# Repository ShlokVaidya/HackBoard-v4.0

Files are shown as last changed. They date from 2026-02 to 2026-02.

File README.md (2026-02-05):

# HackBoard-v4.0

A custom 75% mechanical gaming keyboard featuring a Raspberry Pi Pico 2 microcontroller, VIA keyboard configurator support, and a rotary encoder for media control. This project combines elegant PCB design, modular mechanical construction, and open-source firmware for a fully customizable typing experience.

## Electronics Design

The HackBoard v4.0 uses a matrix-based keyboard design with a Raspberry Pi Pico W as the main controller. Each switch connects to the microcontroller through a matrix circuit, with individual SOD-123 diodes preventing ghosting and ensuring reliable key registration.

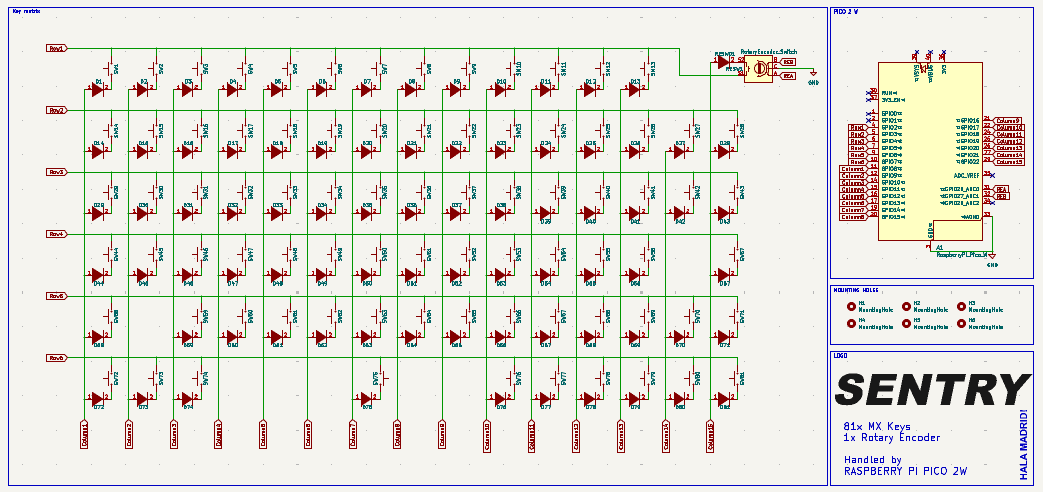
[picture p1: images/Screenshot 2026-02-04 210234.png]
Schematic showing microcontroller and switch matrix connections


The circuit is optimized for minimal latency and power efficiency, with the Pico's USB connectivity enabling VIA firmware for instant key remapping without recompilation.

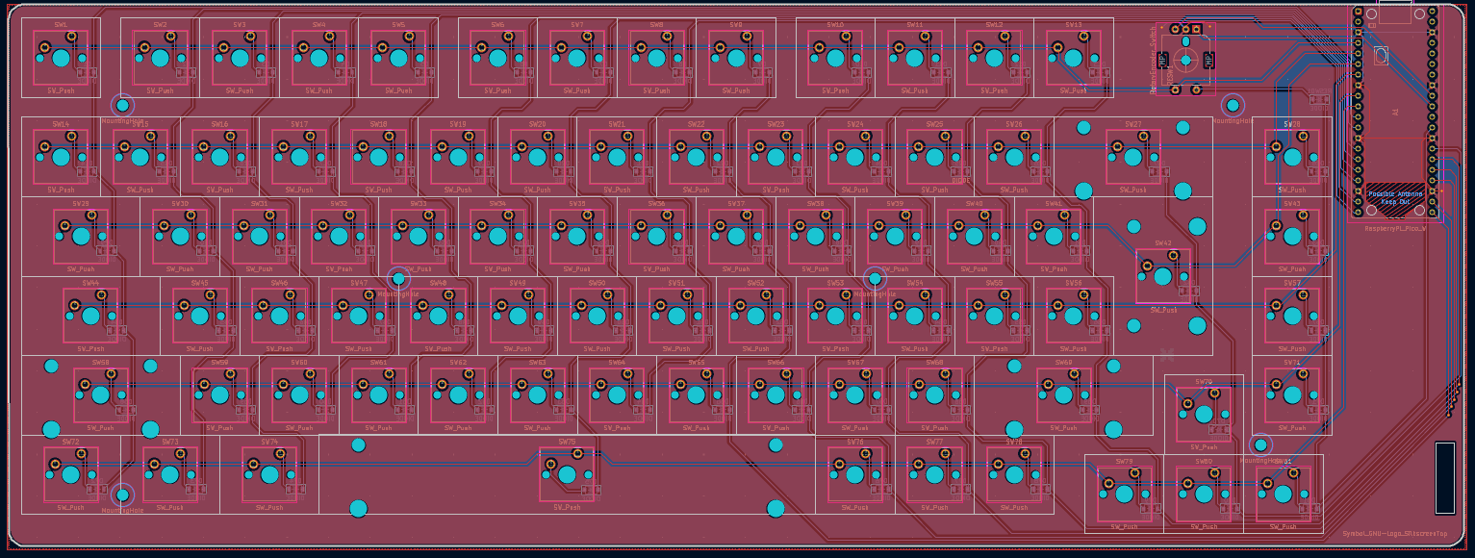
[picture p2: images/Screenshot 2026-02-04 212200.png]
Matrix layout and electrical connections


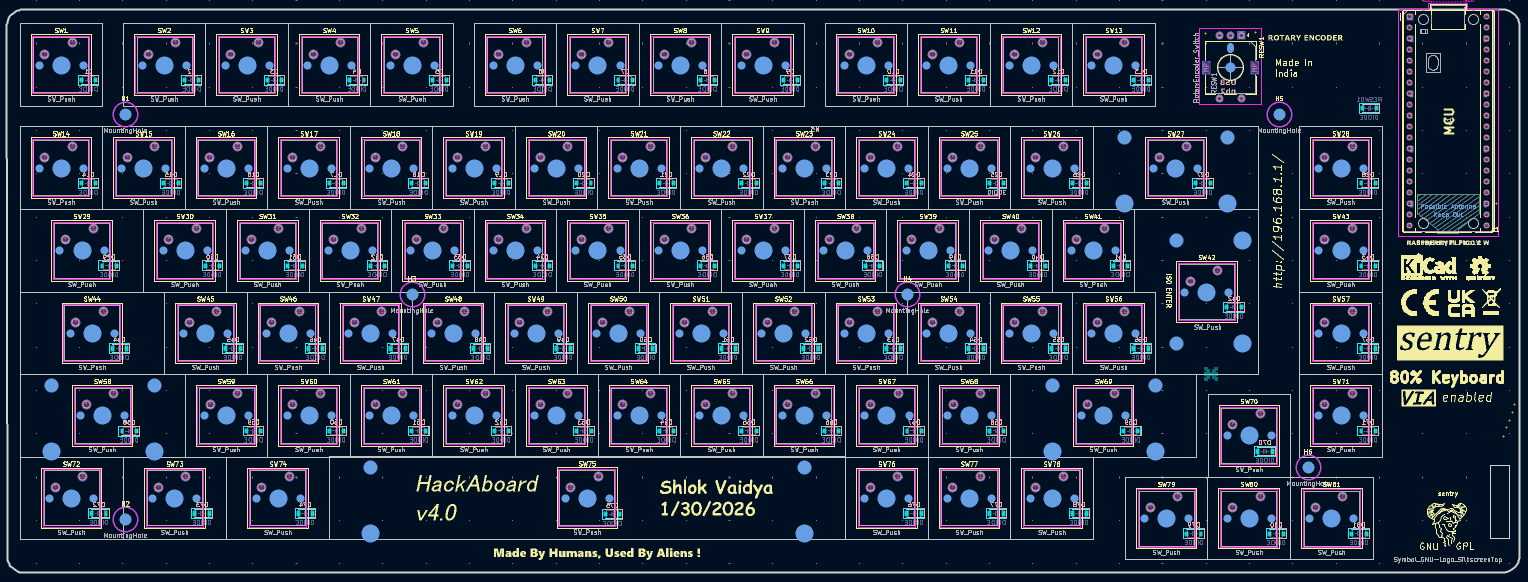
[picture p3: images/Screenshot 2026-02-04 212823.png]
Detailed schematic routing for power distribution and signal integrity


## PCB Design

The PCB is a carefully routed four-layer board that integrates the switch matrix, microcontroller, and rotary encoder in a compact 75% layout. Signal integrity and ground plane continuity were prioritized for minimal EMI and stable operation.

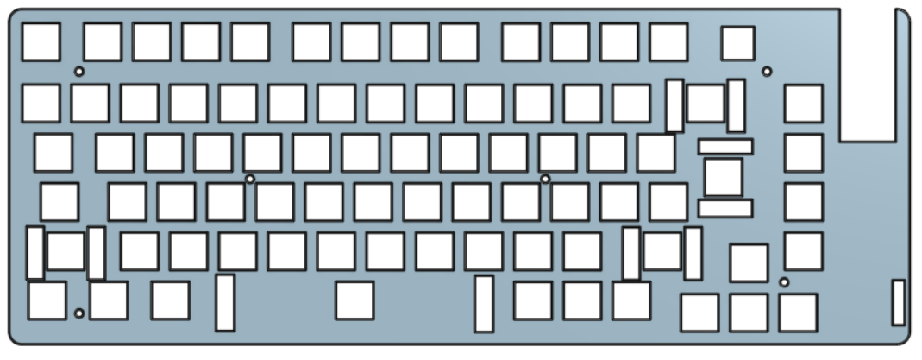
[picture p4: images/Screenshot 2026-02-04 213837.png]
PCB Layout - Component Placement Layer


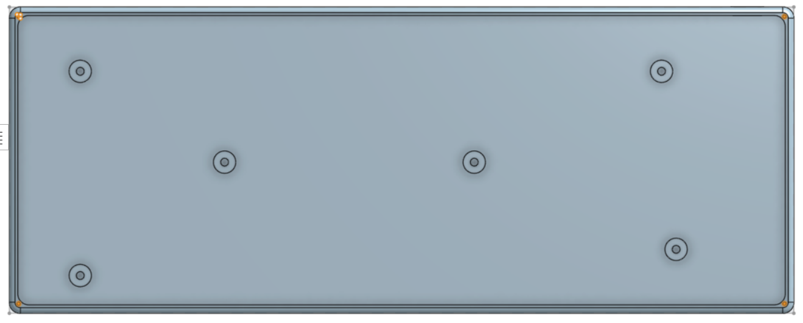
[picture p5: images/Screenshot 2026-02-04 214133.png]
PCB Layout - Top Signal Layer with trace routing


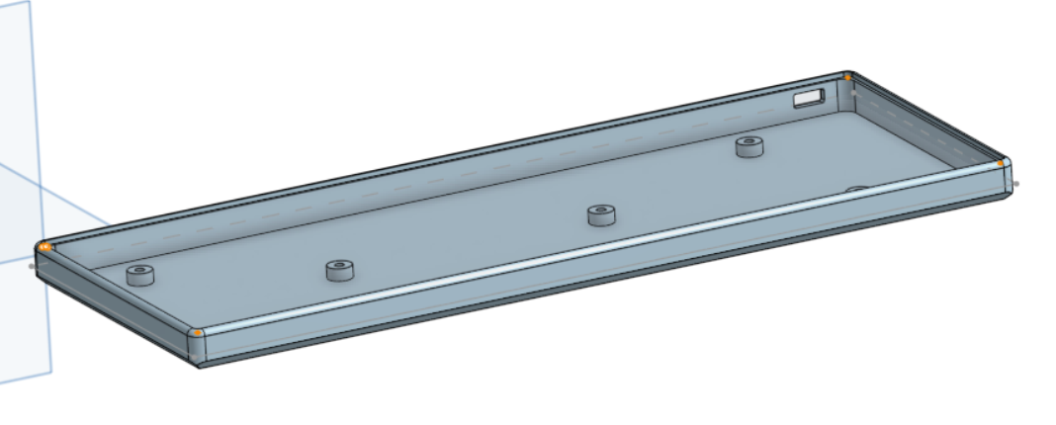
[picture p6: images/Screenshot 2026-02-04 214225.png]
PCB Layout - Bottom Signal Layer showing efficient routing


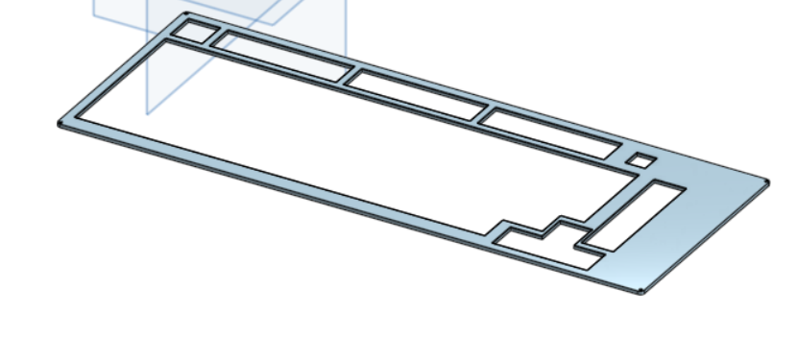
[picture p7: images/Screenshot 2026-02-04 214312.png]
PCB 3D visualization showing component heights and assembly clearance


The design includes mounting points for the stabilizers, hotswap sockets for all key positions, and a dedicated encoder footprint. Via stitching around signal traces ensures proper grounding.

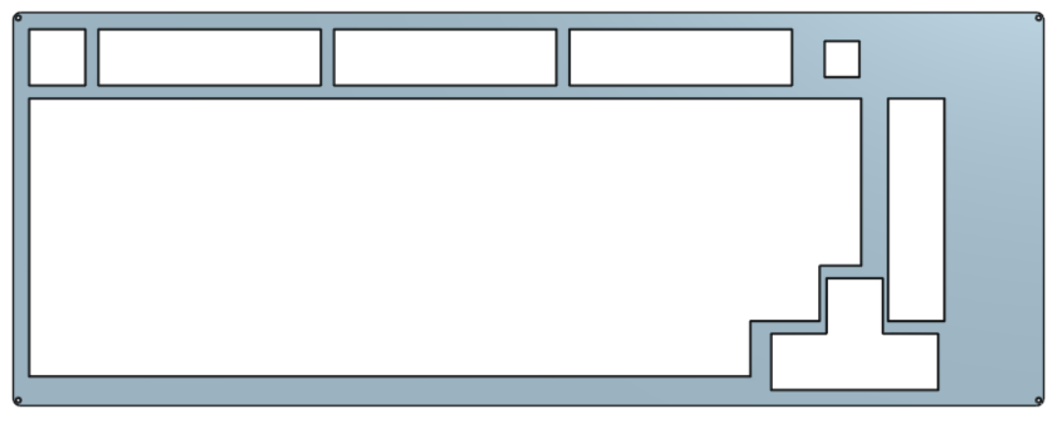
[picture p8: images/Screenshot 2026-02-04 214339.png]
PCB Assembly Layout with component designators


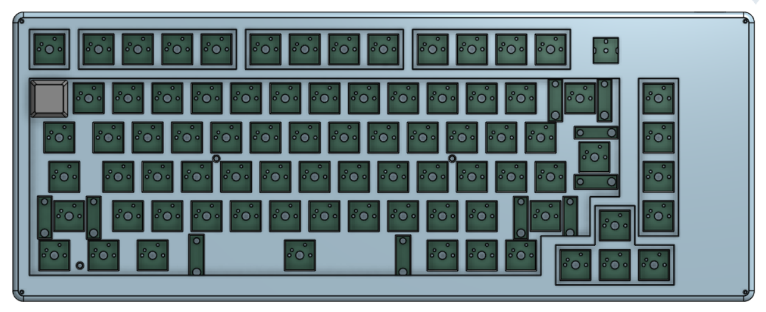
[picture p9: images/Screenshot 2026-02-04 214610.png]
Finished PCB layout ready for fabrication


## Mechanical Design

### Plate Design

The plate provides structural rigidity and supports the stabilizers while maintaining compatibility with Cherry MX switches across all positions.

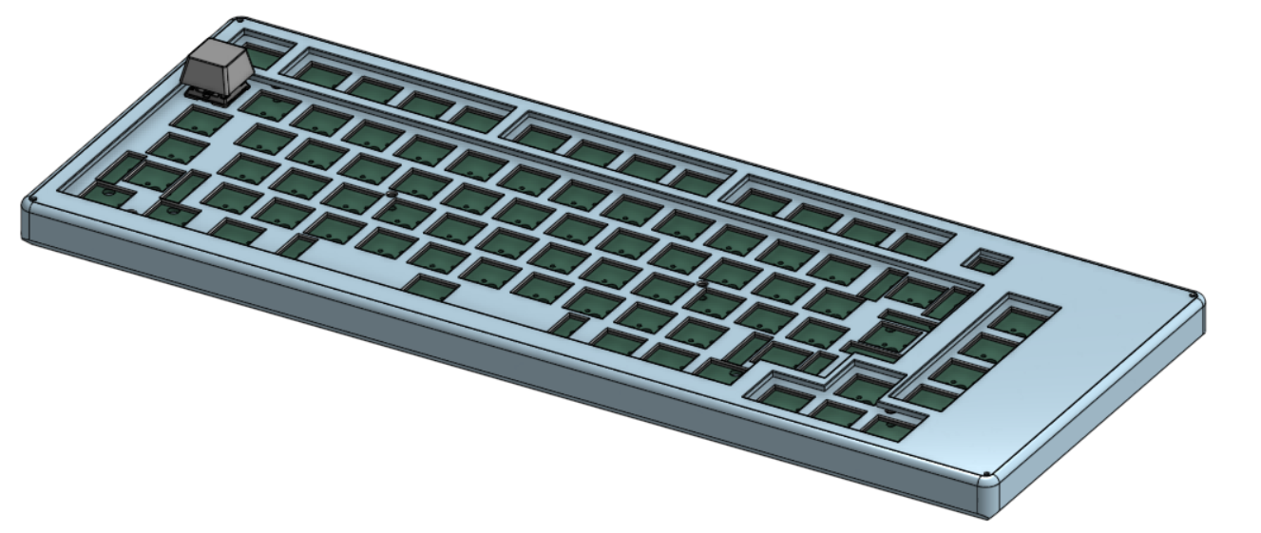
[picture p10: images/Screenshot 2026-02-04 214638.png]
Plate Assembly - Engineering drawing and mounting holes


### Case Design

The case forms the keyboard body and houses the PCB, plate, stabilizers, and all mounting hardware. The design balances acoustics, durability, and aesthetic appeal.

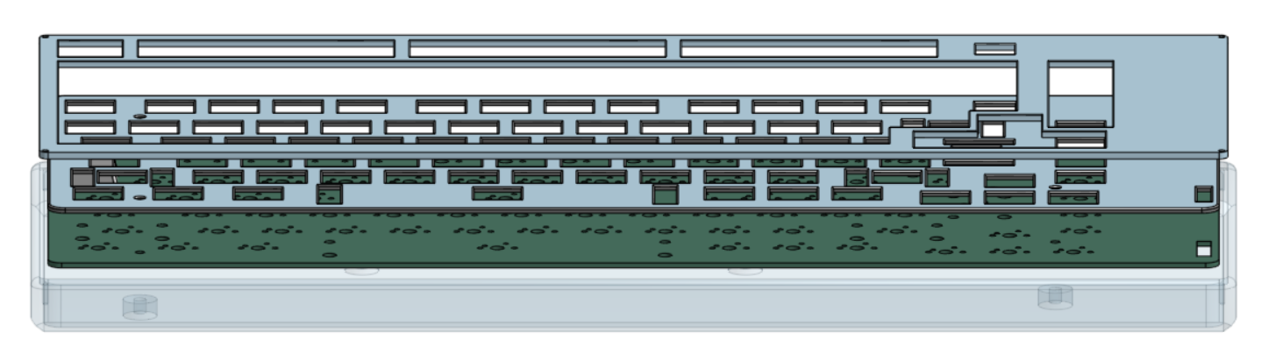
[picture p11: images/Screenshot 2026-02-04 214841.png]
Case - 3D CAD render showing overall form and enclosure


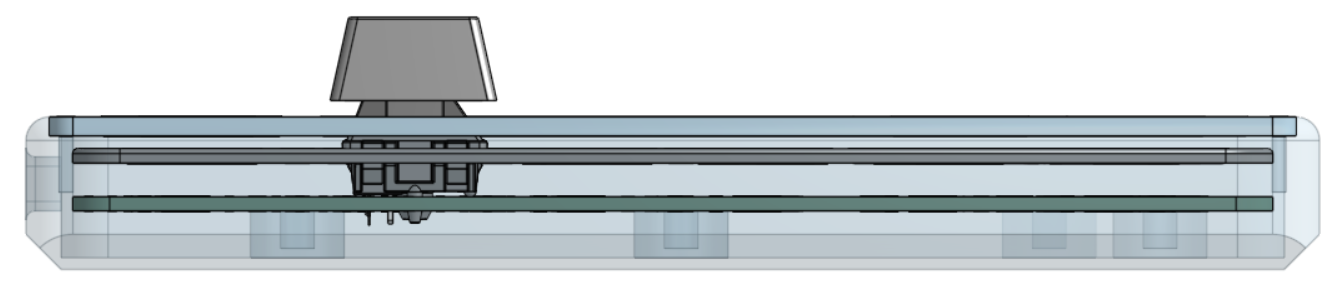
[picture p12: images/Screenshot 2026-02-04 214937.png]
Case - Bottom detail showing mounting features


## Bill of Materials

| Component Name | Qty | Price (₹) | Price ($) | Vendor |
|---|-----|---|---|---|
| Raspberry Pi Pico 2 / Pico 2 W | 1 | ₹635 | $8.00 | [Robu.in](https://robu.in/) |
| Custom 75% Keyboard PCB | 1 | ₹4,692 | $52.00 | [PowerPCB](https://powerpcb.com/) |
| MX Mechanical Switches (Akko V5) | 84 | ₹2,398 | $27.00 | [StacksKB](https://stackskb.com/store/akko-v5-creamy-yellow-pro-switch-pack-of-45/) |
| Clear Screw-In Stabilizer | 4 + 1 (6.25U) | ₹1,595 | $18.00 | [StacksKB](https://stackskb.com/store/durock-clear-screw-in-stabilizers-v2/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) |
| 1N4148W Diodes (SOD-123) | 84 | ₹122 | $1.50 | [Robu.in](https://robu.in/) |
| Rotary Encoder (with push button) | 1 | ₹55 | $1.00 | [Robu.in](https://robu.in/product/hongyan-ec11h-7ce15p1zd15f7-rotary-encoder-with-push-button-switch-vertical-plug-in-5-pin-360-degree/) |
| Keycap Set (75% compatible) | 1 set | ₹2,399 | $27.00 | [Robu.in](https://robu.in/) |
| M2.5 Screws | 7 | ₹43.30 | $0.50 | [OnlyScrews.in](https://onlyscrews.in/) |
| M2.5 Heat-set Inserts | 7 | ₹14.00 | $0.20 | [OnlyScrews.in](https://onlyscrews.in/) |
| M1.6 Screws | 5 | ₹16.00 | $0.20 | [OnlyScrews.in](https://onlyscrews.in/) |
| Shipping (Robu.in) | 1 | ₹49 | $0.59 | [Robu.in](https://robu.in/) |
| Shipping (OnlyScrews.in) | 1 | ₹60 | $0.72 | [OnlyScrews.in](https://onlyscrews.in/) |

---

## Total Cost

**Total (INR): ₹12,078.30**  
**Total (USD): $136.71**

## Project Files

```
PCB/
├── HackBoard v4.kicad_sch    # KiCad schematic
├── HackBoard v4.kicad_pcb    # KiCad PCB layout
├── HackBoard v4.kicad_pro    # KiCad project settings

CAD/
├── Case.step                 # Case 3D model (STEP format)
├── plate.step                # Plate 3D model (STEP format)
├── Top Cover.step            # Top cover 3D model (STEP format)

production/
├── bom.csv                   # Bill of Materials
├── designators.csv           # Component designators
├── positions.csv             # Pick-and-place coordinates
└── netlist.ipc               # IPC netlist format
```

## License

This project is licensed under the MIT License. See [LICENSE](LICENSE) for details.

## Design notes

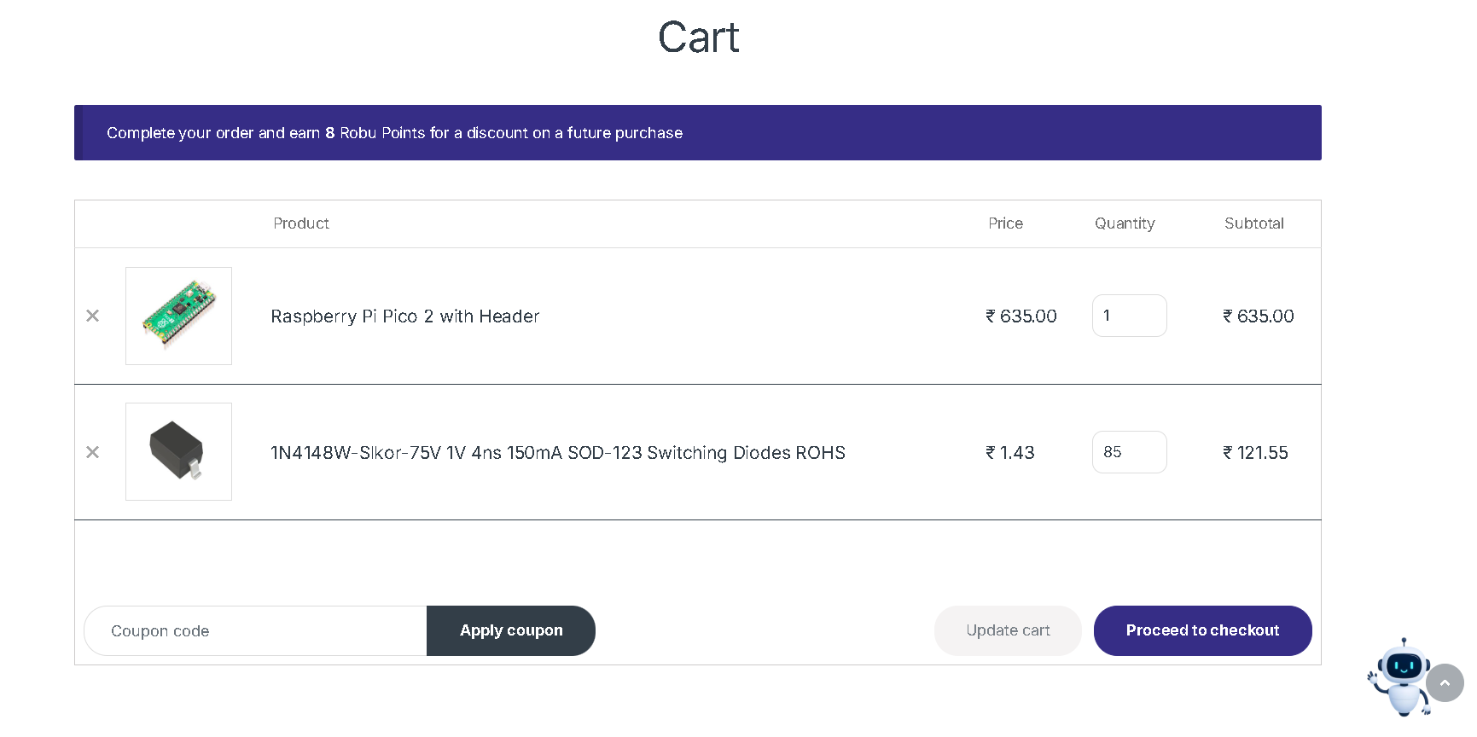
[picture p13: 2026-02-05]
images/Screenshot 2026-02-05 152425.png

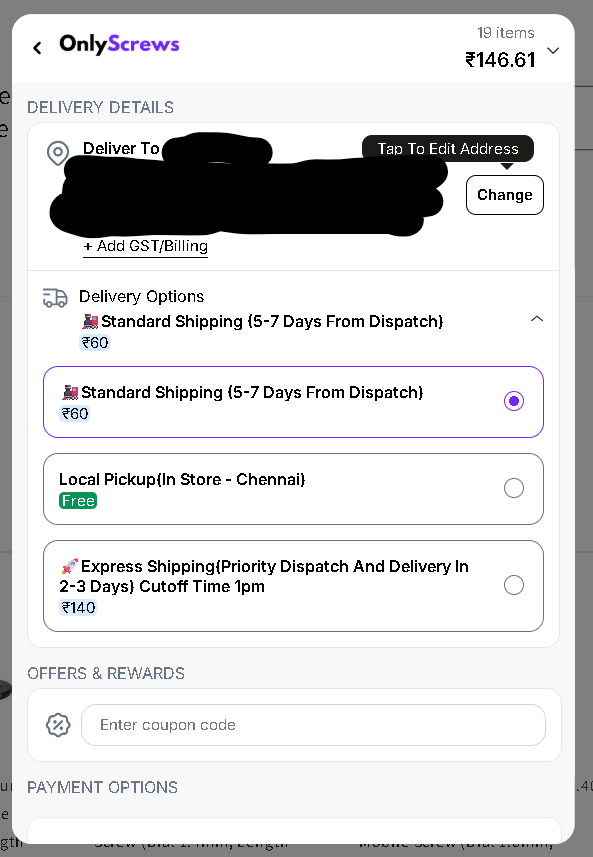
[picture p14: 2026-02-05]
images/Screenshot 2026-02-05 163222.png

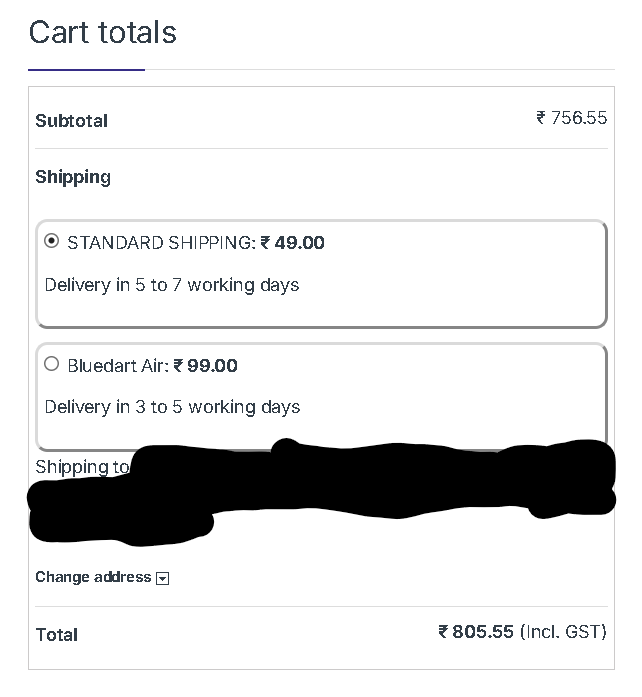
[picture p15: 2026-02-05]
images/Screenshot 2026-02-05 152441.png

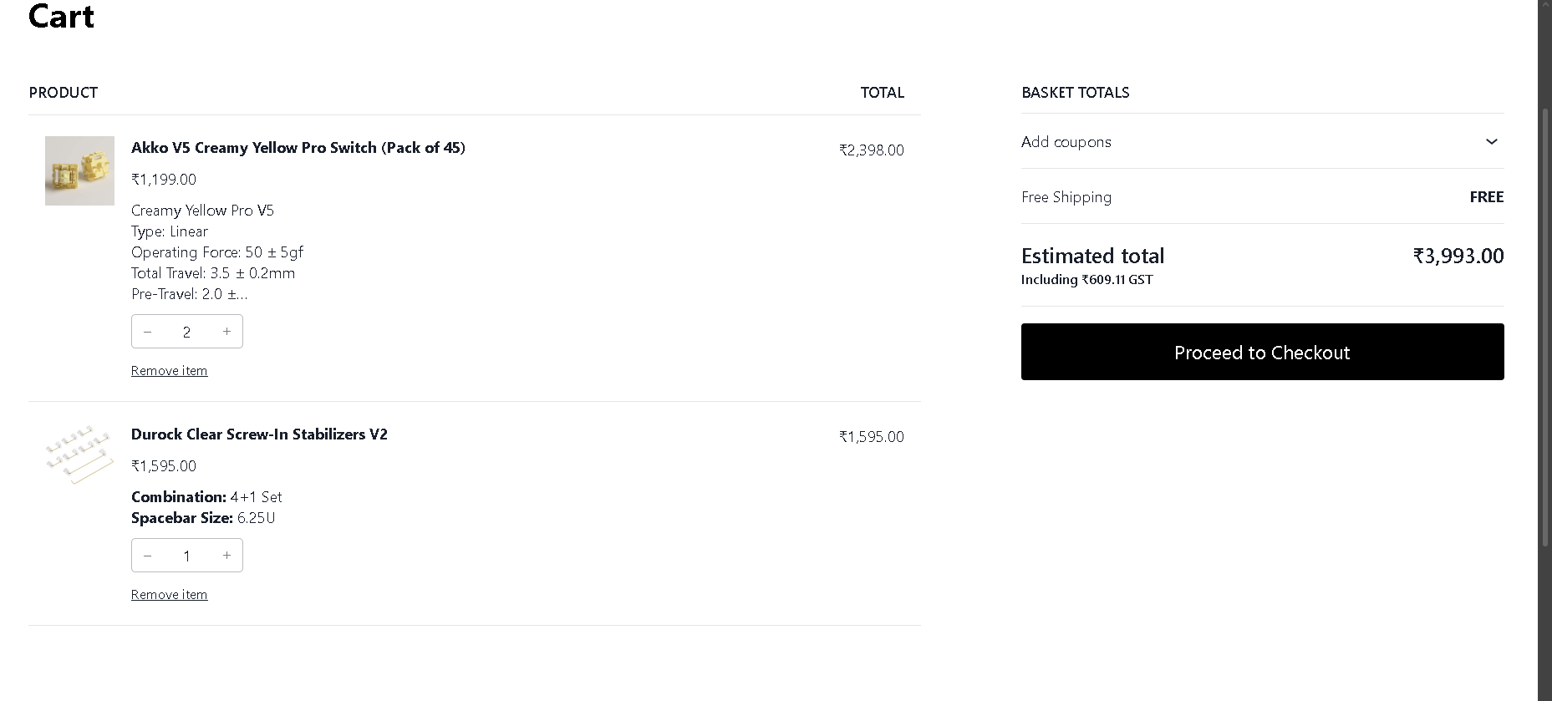
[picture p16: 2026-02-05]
images/Screenshot 2026-02-05 163813.png

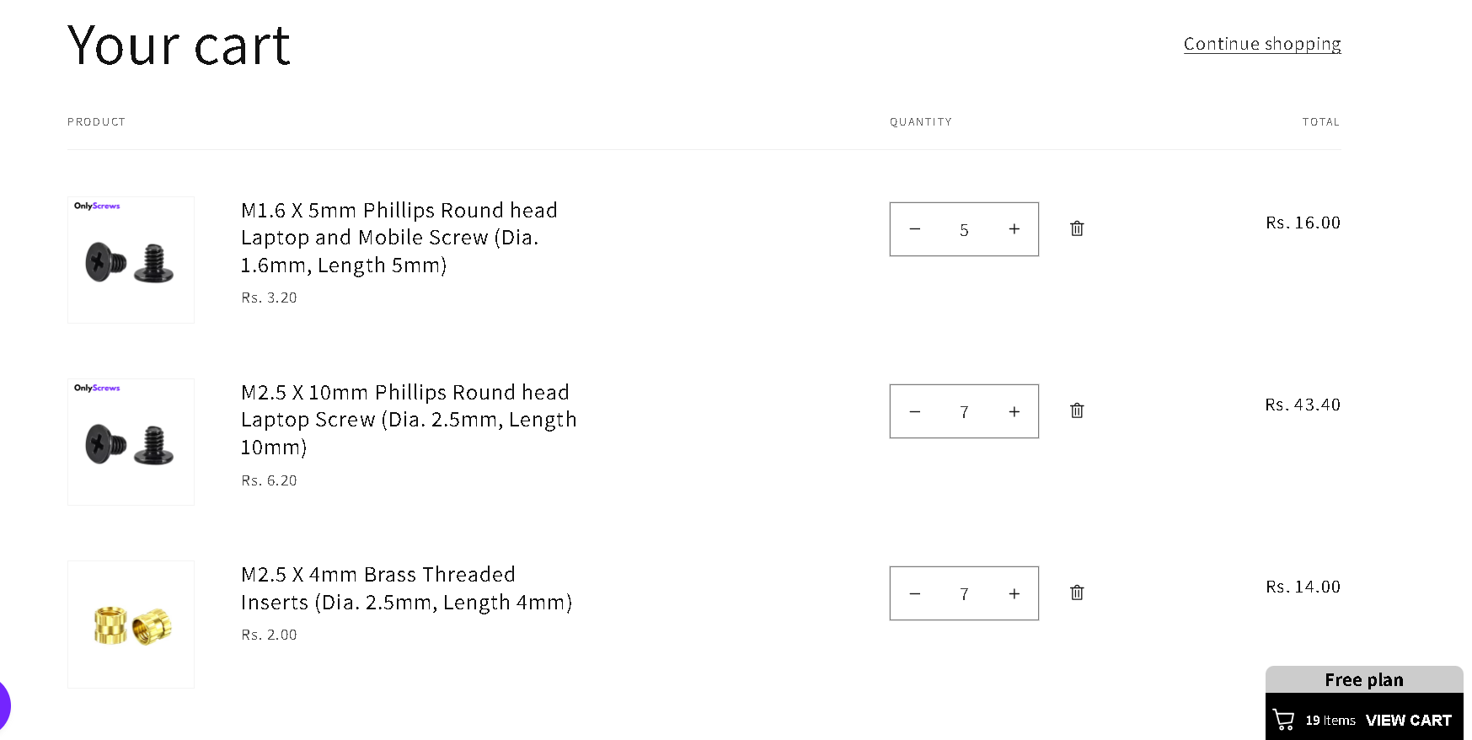
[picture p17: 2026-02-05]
images/Screenshot 2026-02-05 163355.png

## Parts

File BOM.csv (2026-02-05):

Component Name | Qty | Price (₹) | Price ($) | Vendor
Raspberry Pi Pico 2 / Pico 2 W | 1 | 635 | 8.00 | https://robu.in/
Custom 75% Keyboard PCB | 1 | 4692 | 52.00 | https://powerpcb.com/
MX Mechanical Switches (Akko V5) | 84 | 2398 | 27.00 | https://stackskb.com/store/akko-v5-creamy-yellow-pro-switch-pack-of-45/
Clear Screw-In Stabilizer | 4 + 1 (6.25U) | 1595 | 18.00 | https://stackskb.com/store/durock-clear-screw-in-stabilizers-v2/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
1N4148W Diodes (SOD-123) | 84 | 122 | 1.50 | https://robu.in/
Rotary Encoder (with push button) | 1 | 55 | 1.00 | https://robu.in/product/hongyan-ec11h-7ce15p1zd15f7-rotary-encoder-with-push-button-switch-vertical-plug-in-5-pin-360-degree/
Keycap Set (75% compatible) | 1 set | 2399 | 27.00 | https://robu.in/
M2.5 Screws | 7 | 43.30 | 0.50 | https://onlyscrews.in/
M2.5 Heat-set Inserts | 7 | 14.00 | 0.20 | https://onlyscrews.in/
M1.6 Screws | 5 | 16.00 | 0.20 | https://onlyscrews.in/
Shipping (Robu.in) | 1 | 49 | 0.59 | https://robu.in/
Shipping (OnlyScrews.in) | 1 | 60 | 0.72 | https://onlyscrews.in/
TOTAL |  | 12078.30 | 136.71

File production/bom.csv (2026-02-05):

Designator | Footprint | Quantity | Value | LCSC Part #
A1 | RaspberryPi_Pico_Common_THT | 1 | RaspberryPi_Pico_W
D1, D10, D11, D12, D13, D14, D15, D16, D17, D18, D19, D2, D20, D21, D22, D23, D24, D25, D26, D27, D28, D29, D3, D30, D31, D32, D33, D34, D35, D36, D37, D38, D39, D4, D40, D41, D42, D43, D44, D45, D46, D47, D48, D49, D5, D50, D51, D52, D53, D54, D55, D56, D57, D58, D59, D6, D60, D61, D62, D63, D64, D65, D66, D67, D68, D69, D7, D70, D71, D72, D73, D74, D75, D76, D77, D78, D79, D8, D80, D81, D9, RESWD1 | D_SOD-123 | 82 | DIODE
SW1, SW10, SW11, SW12, SW13, SW14, SW15, SW16, SW17, SW18, SW19, SW2, SW20, SW21, SW22, SW23, SW24, SW25, SW26, SW28, SW3, SW30, SW31, SW32, SW33, SW34, SW35, SW36, SW37, SW38, SW39, SW4, SW40, SW41, SW43, SW45, SW46, SW47, SW48, SW49, SW5, SW50, SW51, SW52, SW53, SW54, SW55, SW56, SW57, SW59, SW6, SW60, SW61, SW62, SW63, SW64, SW65, SW66, SW67, SW68, SW7, SW70, SW71, SW76, SW77, SW78, SW79, SW8, SW80, SW81, SW9 | SW_Cherry_MX_1.00u_PCB | 71 | SW_Push
SW27, SW58 | SW_Cherry_MX_2.00u_PCB | 2 | SW_Push
SW29 | SW_Cherry_MX_1.50u_PCB | 1 | SW_Push
SW42 | SW_Cherry_MX_ISOEnter_PCB | 1 | SW_Push
SW44 | SW_Cherry_MX_1.75u_PCB | 1 | SW_Push
SW69 | SW_Cherry_MX_2.25u_PCB | 1 | SW_Push
SW72, SW73, SW74 | SW_Cherry_MX_1.25u_PCB | 3 | SW_Push
SW75 | SW_Cherry_MX_6.25u_PCB | 1 | SW_Push

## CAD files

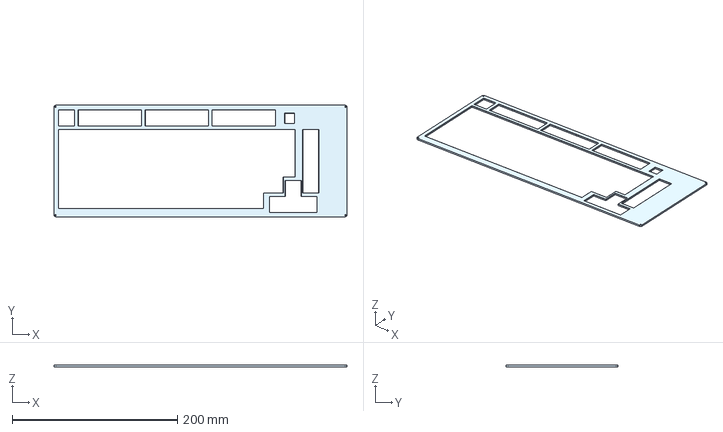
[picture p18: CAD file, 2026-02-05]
CAD/Top Cover.step
354.2 x 135.1 x 2.03 mm

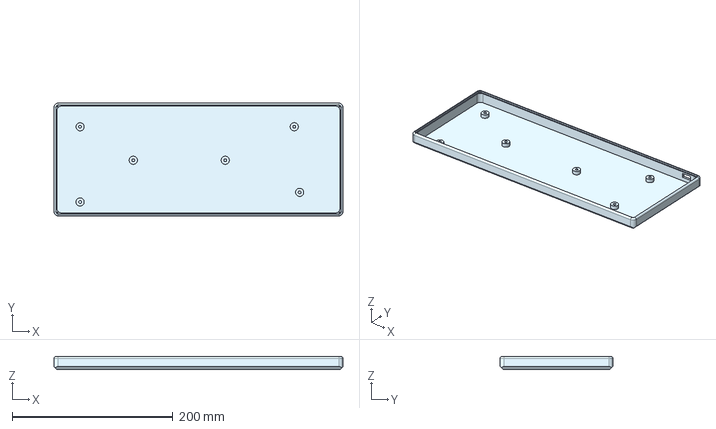
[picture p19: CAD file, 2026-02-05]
CAD/Case.step
359.3 x 140.2 x 16.5 mm

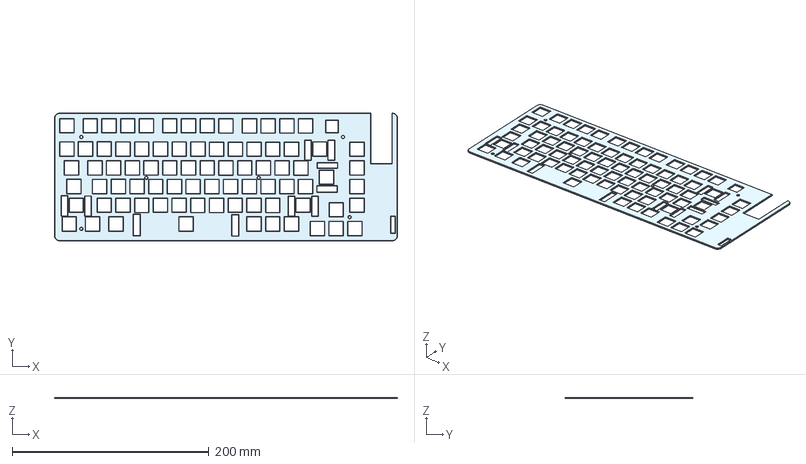
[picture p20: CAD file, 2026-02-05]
CAD/plate.step
349.1 x 130.0 x 1.52 mm

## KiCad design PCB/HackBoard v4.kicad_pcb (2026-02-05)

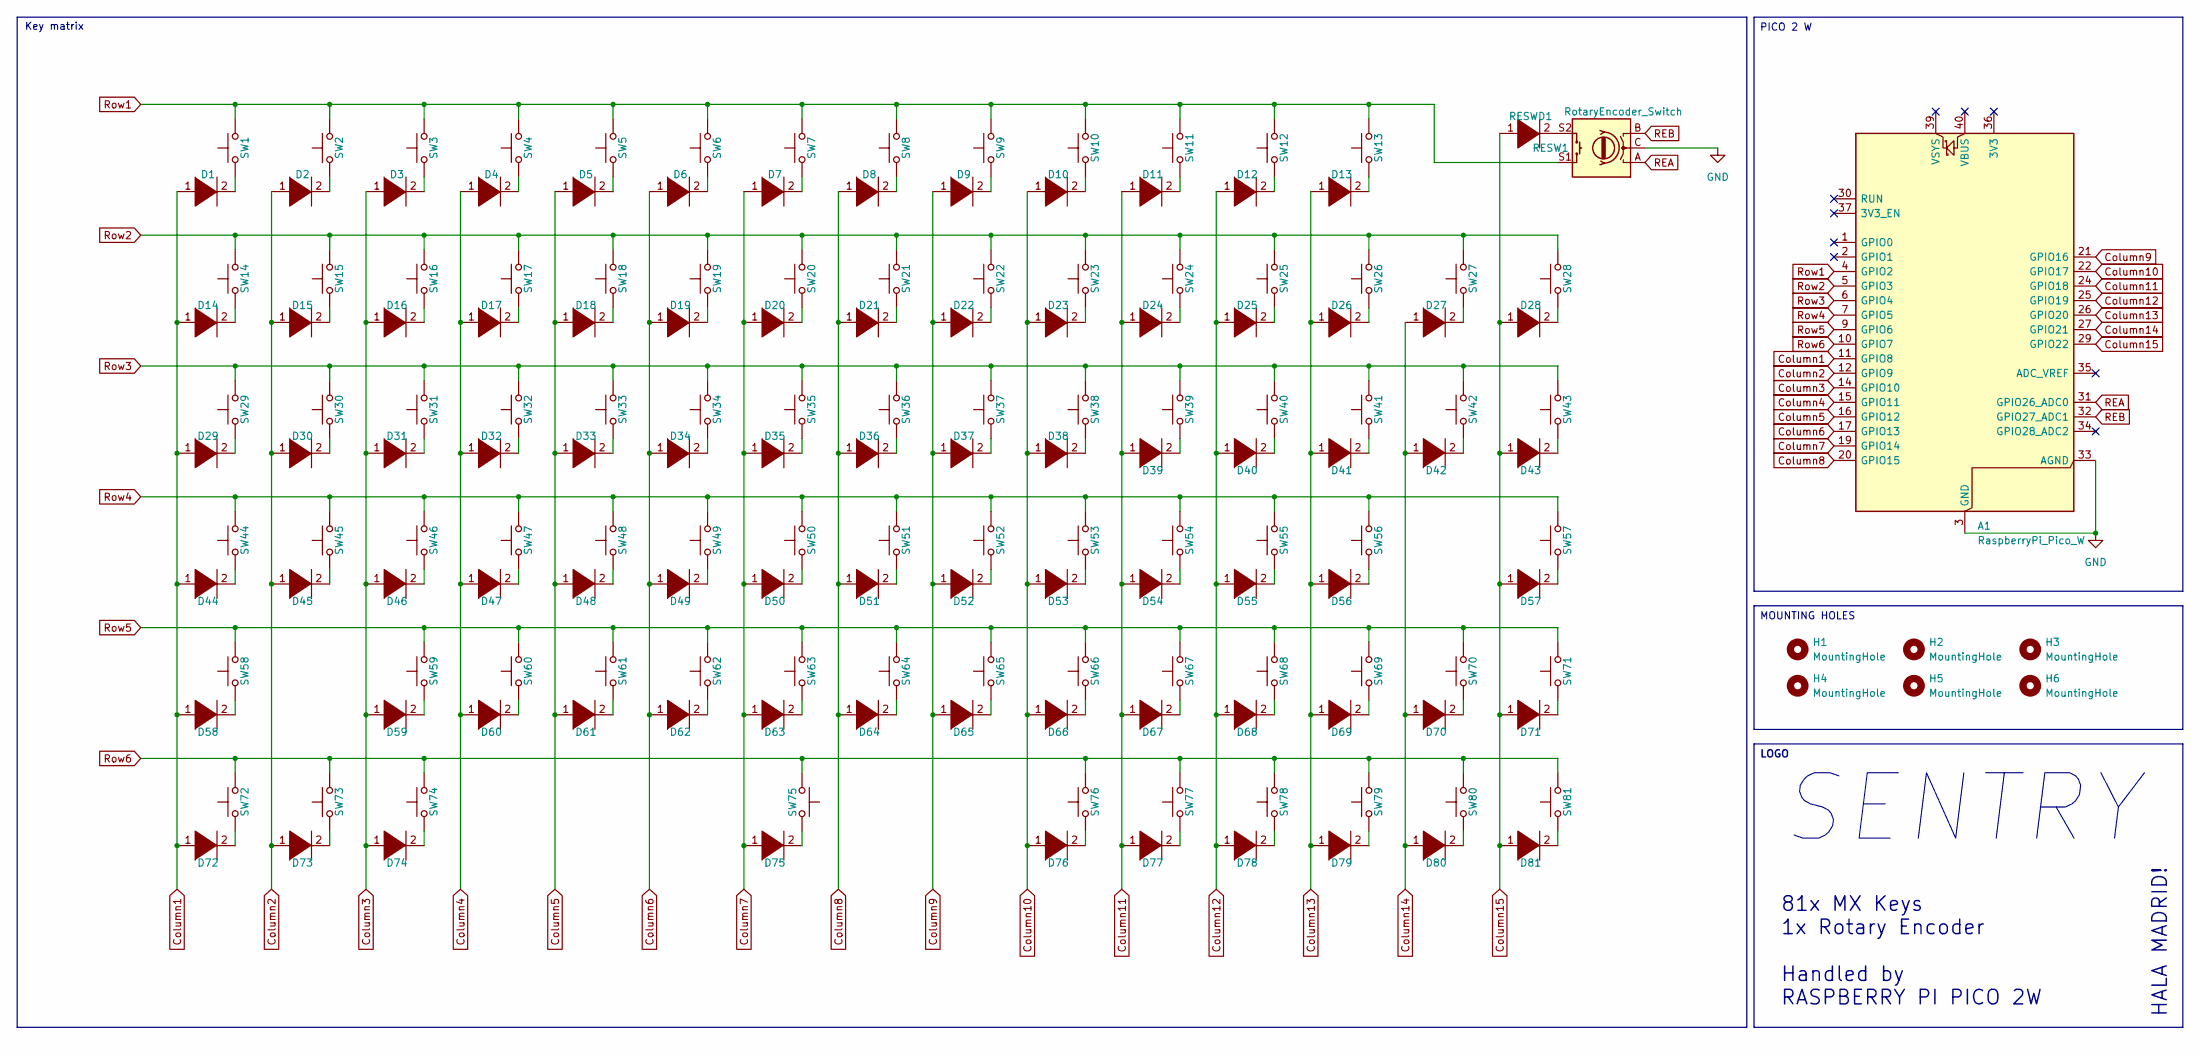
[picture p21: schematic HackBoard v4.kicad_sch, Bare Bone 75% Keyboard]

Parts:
A1: RaspberryPi_Pico_W; RaspberryPi_Pico_Common_THT
D1: DIODE; D_SOD-123; JLCPCB C81598
D2, D3, D4, D5, D6, D7, D8, D9, D10, D11, D12, D13, D14, D15, D16, D17, D18, D19, D20, D21, D22, D23, D24, D25, D26, D27, D28, D29, D30, D31, D32, D33, D34, D35, D36, D37, D38, D39, D40, D41, D42, D43, D44, D45, D46, D47, D48, D49, D50, D51, D52, D53, D54, D55, D56, D57, D58, D59, D60, D61, D62, D63, D64, D65, D66, D67, D68, D69, D70, D71, D72, D73, D74, D75, D76, D77, D78, D79, D80, D81: DIODE; D_SOD-123
H1, H2, H3, H4, H5, H6: MountingHole; MountingHole_2.7mm_M2.5
RESW1: RotaryEncoder_Switch; RotaryEncoder_Alps_EC11E-Switch_Vertical_H20mm_MountingHoles
RESWD1: DIODE; D_SOD-123
SW1, SW2, SW3, SW4, SW5, SW6, SW7, SW8, SW9, SW10, SW11, SW12, SW13, SW14, SW15, SW16, SW17, SW18, SW19, SW20, SW21, SW22, SW23, SW24, SW25, SW26, SW28, SW30, SW31, SW32, SW33, SW34, SW35, SW36, SW37, SW38, SW39, SW40, SW41, SW43, SW45, SW46, SW47, SW48, SW49, SW50, SW51, SW52, SW53, SW54, SW55, SW56, SW57, SW59, SW60, SW61, SW62, SW63, SW64, SW65, SW66, SW67, SW68, SW70, SW71, SW76, SW77, SW78, SW79, SW80, SW81: SW_Push; SW_Cherry_MX_1.00u_PCB
SW27, SW58: SW_Push; SW_Cherry_MX_2.00u_PCB
SW29: SW_Push; SW_Cherry_MX_1.50u_PCB
SW42: SW_Push; SW_Cherry_MX_ISOEnter_PCB
SW44: SW_Push; SW_Cherry_MX_1.75u_PCB
SW69: SW_Push; SW_Cherry_MX_2.25u_PCB
SW72, SW73, SW74: SW_Push; SW_Cherry_MX_1.25u_PCB
SW75: SW_Push; SW_Cherry_MX_6.25u_PCB

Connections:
Column1: A1.11 (GPIO8), D1.1 (K), D14.1 (K), D29.1 (K), D44.1 (K), D58.1 (K), D72.1 (K)
Column2: A1.12 (GPIO9), D2.1 (K), D15.1 (K), D30.1 (K), D45.1 (K), D73.1 (K)
Column3: A1.14 (GPIO10), D3.1 (K), D16.1 (K), D31.1 (K), D46.1 (K), D59.1 (K), D74.1 (K)
Column4: A1.15 (GPIO11), D4.1 (K), D17.1 (K), D32.1 (K), D47.1 (K), D60.1 (K)
Column5: A1.16 (GPIO12), D5.1 (K), D18.1 (K), D33.1 (K), D48.1 (K), D61.1 (K)
Column6: A1.17 (GPIO13), D6.1 (K), D19.1 (K), D34.1 (K), D49.1 (K), D62.1 (K)
Column7: A1.19 (GPIO14), D7.1 (K), D20.1 (K), D35.1 (K), D50.1 (K), D63.1 (K), D75.1 (K)
Column8: A1.20 (GPIO15), D8.1 (K), D21.1 (K), D36.1 (K), D51.1 (K), D64.1 (K)
Column9: A1.21 (GPIO16), D9.1 (K), D22.1 (K), D37.1 (K), D52.1 (K), D65.1 (K)
Column10: A1.22 (GPIO17), D10.1 (K), D23.1 (K), D38.1 (K), D53.1 (K), D66.1 (K), D76.1 (K)
Column11: A1.24 (GPIO18), D11.1 (K), D24.1 (K), D39.1 (K), D54.1 (K), D67.1 (K), D77.1 (K)
Column12: A1.25 (GPIO19), D12.1 (K), D25.1 (K), D40.1 (K), D55.1 (K), D68.1 (K), D78.1 (K)
Column13: A1.26 (GPIO20), D13.1 (K), D26.1 (K), D41.1 (K), D56.1 (K), D69.1 (K), D79.1 (K)
Column14: A1.27 (GPIO21), D27.1 (K), D42.1 (K), D70.1 (K), D80.1 (K)
Column15: A1.29 (GPIO22), D28.1 (K), D43.1 (K), D57.1 (K), D71.1 (K), D81.1 (K), RESWD1.1 (K)
GND: A1.3 (GND), A1.8 (GND), A1.13 (GND), A1.18 (GND), A1.23 (GND), A1.28 (GND), A1.33 (AGND), A1.38 (GND), RESW1.C
unnamed: D1.2 (A), SW1.1
unnamed: D2.2 (A), SW2.1
unnamed: D3.2 (A), SW3.1
unnamed: D4.2 (A), SW4.1
unnamed: D5.2 (A), SW5.1
unnamed: D6.2 (A), SW6.1
unnamed: D7.2 (A), SW7.1
unnamed: D8.2 (A), SW8.1
unnamed: D9.2 (A), SW9.1
unnamed: D10.2 (A), SW10.1
unnamed: D11.2 (A), SW11.1
unnamed: D12.2 (A), SW12.1
unnamed: D13.2 (A), SW13.1
unnamed: D14.2 (A), SW14.1
unnamed: D15.2 (A), SW15.1
unnamed: D16.2 (A), SW16.1
unnamed: D17.2 (A), SW17.1
unnamed: D18.2 (A), SW18.1
unnamed: D19.2 (A), SW19.1
unnamed: D20.2 (A), SW20.1
unnamed: D21.2 (A), SW21.1
unnamed: D22.2 (A), SW22.1
unnamed: D23.2 (A), SW23.1
unnamed: D24.2 (A), SW24.1
unnamed: D25.2 (A), SW25.1
unnamed: D26.2 (A), SW26.1
unnamed: D27.2 (A), SW27.1
unnamed: D28.2 (A), SW28.1
unnamed: D29.2 (A), SW29.1
unnamed: D30.2 (A), SW30.1
unnamed: D31.2 (A), SW31.1
unnamed: D32.2 (A), SW32.1
unnamed: D33.2 (A), SW33.1
unnamed: D34.2 (A), SW34.1
unnamed: D35.2 (A), SW35.1
unnamed: D36.2 (A), SW36.1
unnamed: D37.2 (A), SW37.1
unnamed: D38.2 (A), SW38.1
unnamed: D39.2 (A), SW39.1
unnamed: D40.2 (A), SW40.1
unnamed: D41.2 (A), SW41.1
unnamed: D42.2 (A), SW42.1
unnamed: D43.2 (A), SW43.1
unnamed: D44.2 (A), SW44.1
unnamed: D45.2 (A), SW45.1
unnamed: D46.2 (A), SW46.1
unnamed: D47.2 (A), SW47.1
unnamed: D48.2 (A), SW48.1
unnamed: D49.2 (A), SW49.1
unnamed: D50.2 (A), SW50.1
unnamed: D51.2 (A), SW51.1
unnamed: D52.2 (A), SW52.1
unnamed: D53.2 (A), SW53.1
unnamed: D54.2 (A), SW54.1
unnamed: D55.2 (A), SW55.1
unnamed: D56.2 (A), SW56.1
unnamed: D57.2 (A), SW57.1
unnamed: D58.2 (A), SW58.1
unnamed: D59.2 (A), SW59.1
unnamed: D60.2 (A), SW60.1
unnamed: D61.2 (A), SW61.1
unnamed: D62.2 (A), SW62.1
unnamed: D63.2 (A), SW63.1
unnamed: D64.2 (A), SW64.1
unnamed: D65.2 (A), SW65.1
unnamed: D66.2 (A), SW66.1
unnamed: D67.2 (A), SW67.1
unnamed: D68.2 (A), SW68.1
unnamed: D69.2 (A), SW69.1
unnamed: D70.2 (A), SW70.1
unnamed: D71.2 (A), SW71.1
unnamed: D72.2 (A), SW72.1
unnamed: D73.2 (A), SW73.1
unnamed: D74.2 (A), SW74.1
unnamed: D75.2 (A), SW75.2
unnamed: D76.2 (A), SW76.1
unnamed: D77.2 (A), SW77.1
unnamed: D78.2 (A), SW78.1
unnamed: D79.2 (A), SW79.1
unnamed: D80.2 (A), SW80.1
unnamed: D81.2 (A), SW81.1
unnamed: RESW1.S2, RESWD1.2 (A)
REA: A1.31 (GPIO26_ADC0), RESW1.A
REB: A1.32 (GPIO27_ADC1), RESW1.B
Row1: A1.4 (GPIO2), RESW1.S1, SW1.2, SW2.2, SW3.2, SW4.2, SW5.2, SW6.2, SW7.2, SW8.2, SW9.2, SW10.2, SW11.2, SW12.2, SW13.2
Row2: A1.5 (GPIO3), SW14.2, SW15.2, SW16.2, SW17.2, SW18.2, SW19.2, SW20.2, SW21.2, SW22.2, SW23.2, SW24.2, SW25.2, SW26.2, SW27.2, SW28.2
Row3: A1.6 (GPIO4), SW29.2, SW30.2, SW31.2, SW32.2, SW33.2, SW34.2, SW35.2, SW36.2, SW37.2, SW38.2, SW39.2, SW40.2, SW41.2, SW42.2, SW43.2
Row4: A1.7 (GPIO5), SW44.2, SW45.2, SW46.2, SW47.2, SW48.2, SW49.2, SW50.2, SW51.2, SW52.2, SW53.2, SW54.2, SW55.2, SW56.2, SW57.2
Row5: A1.9 (GPIO6), SW58.2, SW59.2, SW60.2, SW61.2, SW62.2, SW63.2, SW64.2, SW65.2, SW66.2, SW67.2, SW68.2, SW69.2, SW70.2, SW71.2
Row6: A1.10 (GPIO7), SW72.2, SW73.2, SW74.2, SW75.1, SW76.2, SW77.2, SW78.2, SW79.2, SW80.2, SW81.2

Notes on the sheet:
SENTRY
HALA MADRID!
Key matrix
81x MX Keys 1x Rotary Encoder Handled by RASPBERRY PI PICO 2W
PICO 2 W
MOUNTING HOLES
LOGO

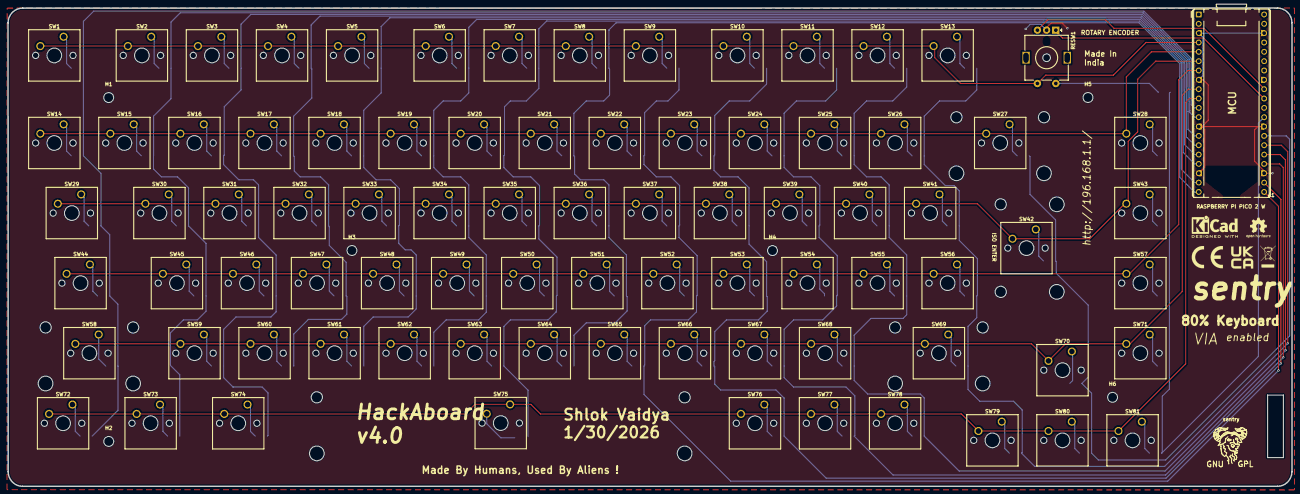
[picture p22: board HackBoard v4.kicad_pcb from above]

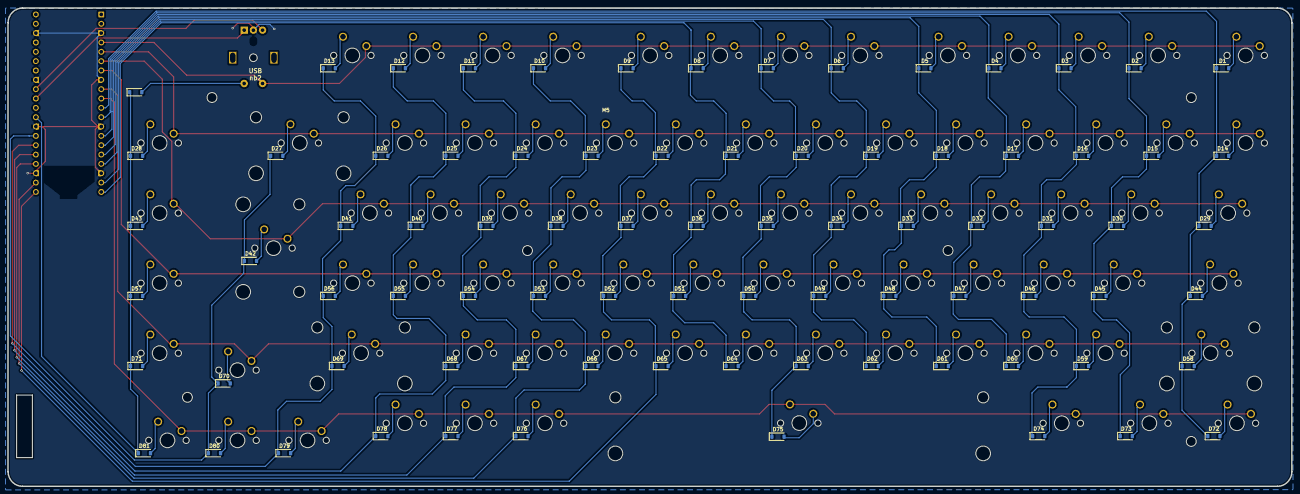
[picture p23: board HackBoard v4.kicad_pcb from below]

Board: 2 copper layers, 349.1 x 130.0 mm, 172 parts (82 on the bottom side), 106 nets.

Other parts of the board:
sentry: Symbol_GNU-Logo_SilkscreenTop

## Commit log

2026-02-05 Added PCB & CAD
    [Case.step, HackBoard v4.kicad_pcb, HackBoard v4.kicad_sch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]
2026-02-05 Updated the README.md
    [BOM.csv]
